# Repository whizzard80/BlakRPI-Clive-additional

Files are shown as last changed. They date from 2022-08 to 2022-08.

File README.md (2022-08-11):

# Build Notes and Information for BlakRPI-CLIVE + any of my updates

## Locate BlakRpi-BOM-UPDATE.xlsx in this repo for the updated BOM

## Original BOM notes
A few parts on the original BOM were either slightly changed or unnecessary.  Likely a few miscellaneous parts from early revisions ended up on the final BOM.  I sorted this out on the update BOM.  I also added anything I noticed was missed or unclear.  The original designer is from France, which explains a few of these small discrepancies.  I wanted to make a clear BOM compatible with Digikey, Mouser, and likely more vendors that accept spreadsheets for BOM lookup.  I will go into the small plug connectors on the board below, the Atmega32U4 chip, and the key switches.

## ATMega32U4
Due to the chip shortage, the IC that is programmed and runs the keyboard can be difficult to find.  However, they should be back in stock more regularly soon because it is such a common IC.  If you are in a pinch, you might be able to salvage one from an Arduino Pro Micro that has on it.  The original BOM calls for the "MU" package, but the "AU" has pins and is easier to solder and probably what the original design was.

## JST/Molex/CNC Tech Connectors + Housings
There are plugs on the board for extra power supplies and USB for plugging into the Pi.  Look into getting a kit of 2.0mm and 2.54mm housings and connectors, there are three-pin, two-pin, and four-pin plugs for lots of expansion, and you can choose how you want to configure the different plugs for your build.  I chose a few right-angle connectors as well.  You can get bundles of these on Amazon or other retailers, or you can pick and choose exactly what you want from a vendor like Mouser.  These are popular in robotics and small electronics, but you will need a crimping tool and pins to assemble your connector cables.   If you don't want to mess with any of that and don't want the modularity, you can solder them directly.  Generic PCB 2.54 headers will help with the 6-pin programmer and mounting the battery charging module.

## Kailh Low profile Mechanical Keyboard Switches

These are super low-profile switches.  Please don't confuse them with the red low-profile Kailh switches.  Only the white will fit.  They are not cheap, probably the most expensive part of the build.  Each switch right now is around one dollar, so a set will cost you 60 dollars at least, but I suggest getting a few extra if you break one or make a mistake.  Here is a link to them on the aliexpress Kailh store: [SwitchLink](https://www.aliexpress.com/item/2251832803593645.html?spm=a2g0o.order_list.0.0.6f4518023p4uJX "Switches")

## Also added my QMK files and hex

blakrpi-clive

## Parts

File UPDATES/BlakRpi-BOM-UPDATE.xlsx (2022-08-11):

Board Reference | Manufacturer Part Number | Mouser Part Number | Digikey Part Number | Description | Quantity | Package | Manufacturer
C1, C2 | C0603C220K8GAC7867 | 80-C0603C220K8GACTU | 399-C0603C220K8GAC7867CT-ND | 22pF | 2 | 0603 | KEMET
C3 | C0603C106M9PAC7867 | 80-C0603C106M9P | 399-C0603C106M9PAC7867CT-ND | 10uF | 1 | 0603 | KEMET
C4, C6, C7 | C0603C104M5RAC7867 | 80-C0603C104M5R | 399-C0603C104M5RAC7867CT-ND | 0.1uF | 3 | 0603 | KEMET
C5 | C0603C105K9RAC7411 | 80-C0603C105K9R7411 | 399-C0603C105K9RAC7411CT-ND | 1uF | 1 | 0603 | KEMET
D1 – D60 | 1N4148WX-TP | 833-1N4148WX-TP | 1N4148WXTPMSCT-ND | SMD Diode | 60 | SOD-323 | Micro Commercial Co
R1, R2 | RN73C1J10KBTG | 279-RN73C1J10KBTG | A105758-ND | 10K | 2 | 0603 | TE Connectivity
R3, R4 | CRGP0603F22R | 279-CRGP0603F22R | A130396CT-ND | 22r | 2 | 0603 | TE Connectivity
R5 – R9 | CPF0603B2K0E | 279-CPF0603B2K0E | A119958CT-ND | 2K | 5 | 0603 | TE Connectivity
R10-R64 (KB-LEDs) | APT1608LVBC/D | 604-APT1608LVBCD | 754-1933-1-ND | 2mA LED (Blue) | 60 | 0603 | Kingbright
R65, R66 | ERJ-PB3D5101V | 667-ERJ-PB3D5101V | P20363CT-ND | 5.1K | 2 | 0603 | Panasonic
J7 | B2B-PH-SM4-TB(LF)(SN) | na | 455-1734-1-ND | 01x02 SMT JST Battery Connector | 1 | JST-PH 2.0mm | JST
J4 | KUSBX-SMT-CS2-B30TR | 806-KUSBXSMTCS2B30TR | 2092-KUSBX-SMT-CS2-B30TR-ND | Female USB-C Receptacle SMT Pins | 1 | Type-C Right Angle, Surface Mount | Kycon
J11 | 1-292303-6 | 571-1-292303-6 | A118230TR-ND | USB-A Plug | 1 | Surface Mount, Right Angle | TE Connectivity
Keyboard Switches | CPG123201D01 |  |  | Kailh Low profile Mechanical Keyboard Switch for Laptop and Portables | 60 | 14.5x13.5x8.2mm | Be sure you get the laptop type switch, the other low profile will not work. They are white colored switches.
KbCnx | DS04-254-1-02BK-SMT | 490-DS04254102BK-SMT | 2223-DS04-254-1-02BK-SMT-ND | Dip Switch for KB Cnx | 1 | PCB Mount | CUI Devices
Y1 | HC-49/U-S16000000ABJB | 695-HC49US16.0ABJB | 300-6034-ND | Crystal Oscillator | 1 | Through-Hole | Citizen
Reset Button | B3U-1000P | 653-B3U-1000P | SW1020CT-ND | SPST Tactile Switch | 1 | SMD (SMT) Tab (Off-Mom) | Omron
U1 | ATmega32U4 | 556-ATMEGA32U4RC-AU | ATMEGA32U4-AU-ND | 16Mhz AVR KB Controller *see notes | 1 | TQFP-44_10x10mm_P0.8mm | Atmel
U2 (display screen) | 8.8" 1920x480 Stretched Bar Display IPS LCD Screen |  |  | 8.8 inch 1920x480 Stretched Bar Display IPS LCD Screen 60hz Automotive Adjustable MIPI Controller Board WLED Backlight for Aida64 Raspberry Pi | 1 | Screen w/ optional capacitive touch (see listing) | https://www.aliexpress.com/item/3256801123397976.html?spm=a2g0o.order_list.0.0.74ad1802u2G6EJ
U3 (MIPI Board for screen) |  |  |  |  | 1 | Check listing, should come with the screen
PCB Mounting Hardware for MIPI Board | 9774005243R | 710-9774005243R | 732-9774005243RCT-ND | M2 screw PCB attach spacers | 4 | Best fit get M2-0.4 X 3mm screws to attach to these | Wurth
U4 | Battery Protection / Charger |  |  | 2A 5V Charge Discharge Integrated 3.7V 4.2V Lithium Battery Boost Mobile Power Protection Diy Electronic PCB Board Module | 1 |  | https://www.aliexpress.com/item/2251832812803953.html
Battery |  |  |  | 3.7V 12000mAh Lithium polymer Battery with Protection Board | 1 | 135mmx68mmx9mm | https://www.aliexpress.com/item/2251832649004857.html?spm=a2g0o.order_list.0.0.6f4518023p4uJX
RPI_Connector-ML_Rpi_GPIO | Adafruit Product ID: 2187 |  |  | Surface-Mount RPI Connector | 1 | SMT GPIO Header for Raspberry Pi HAT - 2x20 Short Female Header | Adafruit – https://www.adafruit.com/product/2187
PCB Mount Headers | TSW-112-08-H-D-RA | 200-TSW11208HDRA |  | Classic Generic PCB headers for serial programmer and possibly for led and on/off switch | 1 | 2.54mm Pitch PCB mount through-hole headers
USB-Serial Programmer | USBasp_H6 Programmer + 6 pin Cable |  |  | USBasp H6 programmer for flashing the atmega32u4 | 1 | Can confirm this “DollaTek” model on Amazon works. | https://www.amazon.com/DollaTek-USBASP-USBasp_H6-Programmer-Support/dp/B07DK5M7LZ
Connector Plugs |  |  |  |  |  | See build-readme.md on suggestions for JST, Molex,

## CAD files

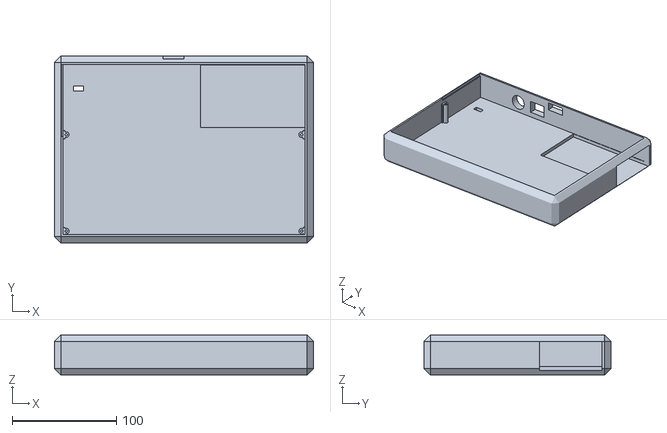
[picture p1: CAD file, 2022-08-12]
UPDATES/blakrpi-case.stl
248.0 x 179.0 x 38.0

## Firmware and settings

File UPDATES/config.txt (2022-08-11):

# For more options and information see
# http://rpf.io/configtxt
# Some settings may impact device functionality. See link above for details

# uncomment if you get no picture on HDMI for a default "safe" mode
#hdmi_safe=1

# uncomment the following to adjust overscan. Use positive numbers if console
# goes off screen, and negative if there is too much border
overscan_left=16
overscan_right=16
overscan_top=8
overscan_bottom=16

# uncomment to force a console size. By default it will be display's size minus
# overscan.
#framebuffer_width=1280
#framebuffer_height=720

# uncomment if hdmi display is not detected and composite is being output
#hdmi_force_hotplug=1

# uncomment to force a specific HDMI mode (this will force VGA)
#hdmi_group=1
#hdmi_mode=1

# uncomment to force a HDMI mode rather than DVI. This can make audio work in
# DMT (computer monitor) modes
#hdmi_drive=2

# uncomment to increase signal to HDMI, if you have interference, blanking, or
# no display
#config_hdmi_boost=4

# uncomment for composite PAL
#sdtv_mode=2

#uncomment to overclock the arm. 700 MHz is the default.
#arm_freq=800

# Uncomment some or all of these to enable the optional hardware interfaces
dtparam=i2c_arm=on
#dtparam=i2s=on
dtparam=spi=on

# Uncomment this to enable infrared communication.
#dtoverlay=gpio-ir,gpio_pin=17
#dtoverlay=gpio-ir-tx,gpio_pin=18

# Additional overlays and parameters are documented /boot/overlays/README

# Enable audio (loads snd_bcm2835)
dtparam=audio=on

# Automatically load overlays for detected cameras
camera_auto_detect=1

# Automatically load overlays for detected DSI displays
display_auto_detect=1

# Enable DRM VC4 V3D driver
#dtoverlay=vc4-kms-v3d
#max_framebuffers=2

# Disable compensation for displays with overscan
#disable_overscan=1

[cm4]
# Enable host mode on the 2711 built-in XHCI USB controller.
# This line should be removed if the legacy DWC2 controller is required
# (e.g. for USB device mode) or if USB support is not required.
otg_mode=1

[all]

[pi4]
# Run as fast as firmware / board allows
arm_boost=1

[all]
dtoverlay=w1-gpio
enable_uart=1
avoid_warnings=1
# These lines for 1920x480 display
max_framebuffer_height=1920
hdmi_ignore_edid=0xa5000080
hdmi_timings=480 1 48 32 80 1920 0 3 10 56 0 0 0 60 0 75840000 3
hdmi_group=2
hdmi_mode=87
hdmi_force_mode=1
hdmi_drive=2
config_hdmi_boost=4
display_hdmi_rotate=3

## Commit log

2022-08-11 Uploaded some files
    Updated BOM and my updated QMK files
    [BlakRpi-BOM-UPDATE.xlsx]
2022-08-11 Created UPDATE folder
    created folder of updates / changes
    [BlakRpi-BOM-UPDATE.xlsx]
2022-08-11 Rpi config.txt for display
    RPI config.txt for panoramic display
    [config.txt]
2022-08-12 Added 3d print case STL
    I modified a few parts of the case for stability and better fit
    [blakrpi-case.stl]
2022-08-12 Delete blakrpi-case.stl
    updated stl
    [blakrpi-case.stl]
2022-08-12 updated blakrpi case STL file
    Updated the 3D print case file, not printed yet
    [blakrpi-case.stl]
